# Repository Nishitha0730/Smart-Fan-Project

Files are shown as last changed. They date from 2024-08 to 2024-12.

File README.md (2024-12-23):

# About my first project on Semester 2 

# Smart Fan Project

Our Smart Fan is a temperature and occupancy-based automation system designed to optimize energy efficiency in public spaces. The project addresses the common issue of fans being left on unnecessarily, either due to forgetfulness or lack of automation.

Motivation
This project was inspired by the need to reduce energy wastage in public places where fans often operate even without human presence. By automating fan operation based on temperature and occupancy, the Smart Fan provides a more sustainable and user-friendly solution.

My Contribution
1. Enclosure Design
Designed a durable and stable enclosure using SolidWorks to support the weight of the fan motor and the rotational forces of the fan.
Due to 3D printer size constraints (24 cm height limit), the enclosure was split into two parts for manufacturing.
Utilized epoxy plastic glue and screws to securely join the two printed parts.
2. Circuit Diagram Development
Contributed to designing the circuit diagram, ensuring smooth integration with sensors and the fan's control system.

Through this project, I developed skills in enclosure design, 3D printing, and basic circuit design. These experiences have strengthened my foundation in hardware development and collaboration in team projects.

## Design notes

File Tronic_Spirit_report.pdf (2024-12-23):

## University of Moratuwa

## Faculty of Engineering

## Department of Electronic and Telecommunication Engineering


## EN 1190:Engineering Design Project

## Tronic Spirit

## Automatic Fan Controlling System along with Typical Fan Controller

Group Members

Index No | Name
220379N | Malshan K.K.R
220380J | Manawadu.D.N
220498D | Rajakaruna.R.W.M.D.S
220481U | Pitigala P.K.N.W.

## ABSTRACT

Our automatic fan controller is designed to minimize electricity wastage by regulating fan usage, particularly in public settings. The fan is designed to power down automatically in the absence of human presence, effectively reducing energy wastage. Additionally, it has the capability to adapt its speed based on external temperatures automatically, thus providing added convenience to users, especially during busy moments. This product is suitable for countries like Sri Lanka, where energy conservation is crucial. Moreover, its automatic speed adjustment feature further enhances user convenience. We plan to collaborate with major fan manufacturers to integrate our product into their fan systems. In our upcoming projects, we aim to enhance the standard fan controller and extend our project concept to include ceiling fans and wall-hanging fans.

## Table of Contents

### 1 Problem Description

### 1.1 Arriving at a Problem

We often see electronic equipment such as fans working in public places even when people aren’t around, resulting in energy wastage. Additionally, adjusting the fan’s speed during busy moments can be quite bothersome. Our product addresses these issues and provides an innovative solution.

### 1.2 Arriving at a Solution

Our automatic fan is designed to detect the presence of humans in a certain area and automatically power down when no one is detected in the vicinity. This helps reduce energy wastage by automatically turning off the fan when unnecessary. Our system also adjusts the fan speed according to the external temperature, eliminating the need for manual intervention.

### 1.3 Motivation

Seeing how fans and other electronic equipment were vainly switched on in public places such as lecture halls motivated us to create this product. The product aims to improve energy efficiency, reduce costs, and enhance user convenience.

### 1.4 Justification for Selection

We conducted a survey aimed at potential users, and the results validated our product. The survey revealed that the majority of respondents have noticed fans working unnecessarily in public places, admitted to forgetting to switch fans off when leaving, and found manually adjusting fan speed troublesome. Therefore, the survey justifies the importance of our product.

### 2 Feasibility

### 2.1 Technical Feasibility

### 2.1.1 Hardware Feasibility

Our product utilizes sensors to monitor temperature and human presence. We used two PIR sensors (Passive Infrared sensors) to detect human presence and selected the DHT11 temperature sensor to accurately track room temperature. The ATMEGA 328 microcontroller processes sensor data and controls the fan. Other hardware components include relays and push-button switches. The PCB interconnects all modules, and all hardware components are easily accessible and cost-effective, making our product feasible.

### 2.1.2 Software Feasibility

Our product was designed using Altium Designer and we used LTSPICE for simulations. We used Arduino IDE to program the microcontroller and SolidWorks for enclosure design. The software used is easy to use, making the product highly feasible in terms of software.

### 2.2 Economic Feasibility

Our product offers long-term benefits, such as lower electricity bills due to reduced energy consumption and a positive environmental impact with a lower carbon footprint, resulting in environmental sustainability. Although the initial cost might be higher than traditional fans, the long-term energy savings and environmental benefits make it economically feasible. The growing demand for smart home and office solutions further enhances its economic viability.

### 3 Architecture

The arrangement of the relays, configuration of the power supply unit, and microcontroller chip are as follows:

### 3.1 Subsystems Included in the Design

- Power Supply Module: Powers all components.
- Sensing Module: Includes sensors like the DHT11 temperature sensor and the PIR sensor used to monitor environmental parameters and detect human presence, respectively.
- Actuation Module: Connected to the microcontroller’s output pins and power supply, includes relays that regulate the fan’s speed and power based on sensor signals.
- User Interface Module: Includes the control panel with buttons for manual control, connected to the microcontroller to receive user inputs.
- Main PCB: Connects all components and subsystems with the microcontroller.

### 3.2 Wiring Diagram

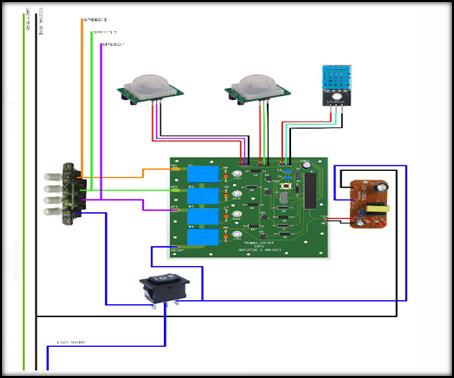
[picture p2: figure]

Figure 1: Overall Wiring Diagram

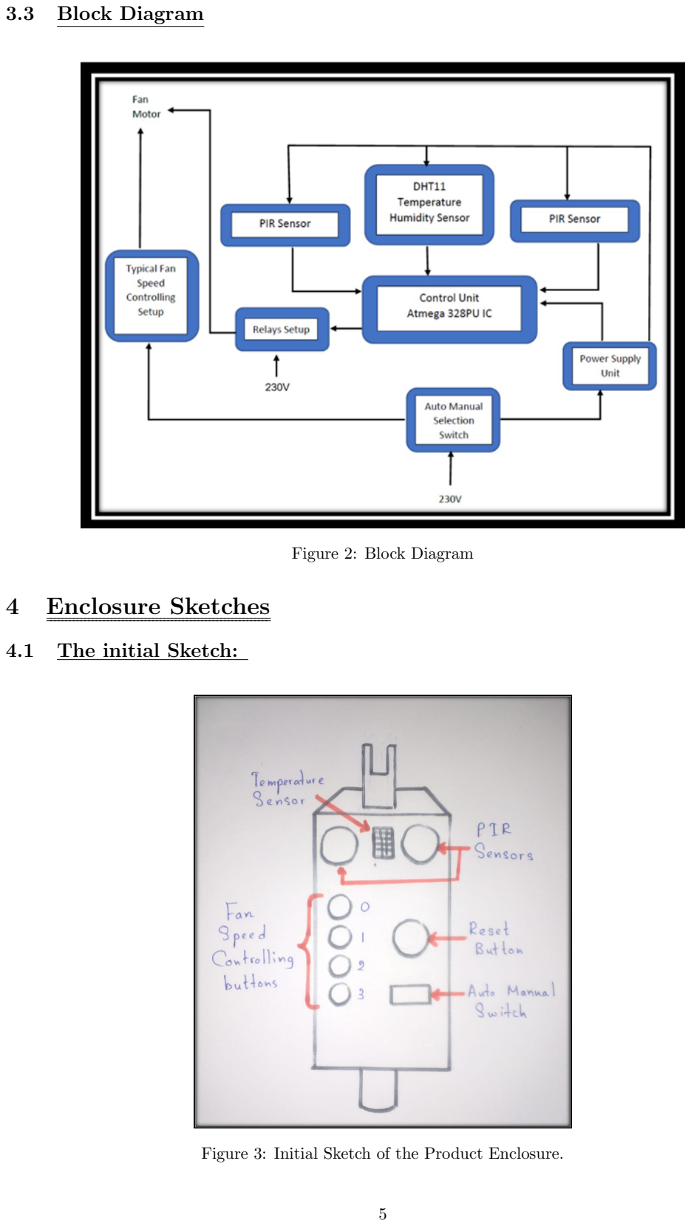
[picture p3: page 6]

### 3.3 Block Diagram

Figure 2: Block Diagram

### 4 Enclosure Sketches

### 4.1 The initial Sketch:

Figure 3: Initial Sketch of the Product Enclosure.

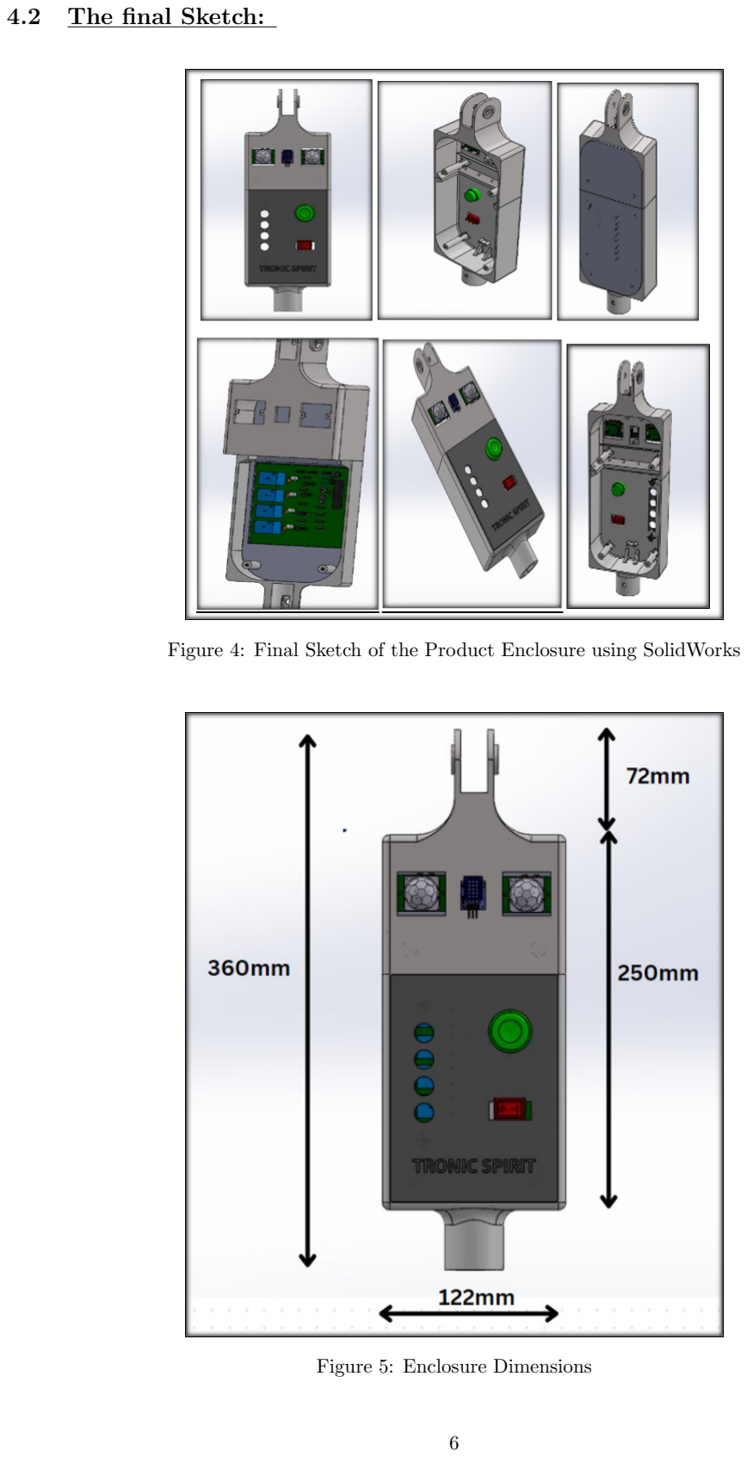
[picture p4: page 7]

### 4.2 The final Sketch:

Figure 4: Final Sketch of the Product Enclosure using SolidWorks

Figure 5: Enclosure Dimensions

### 5 PCB Design

### 5.1 PCB layout

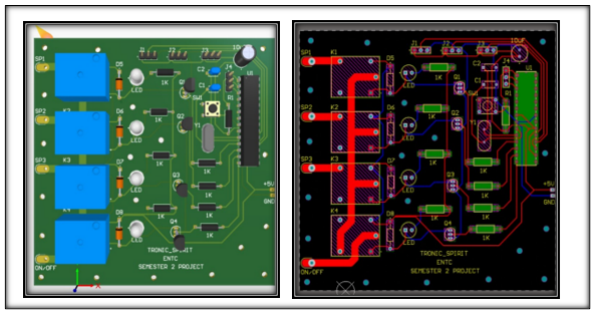
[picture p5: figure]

Figure 6: PCB Layout

### 5.2 PCB Schematic

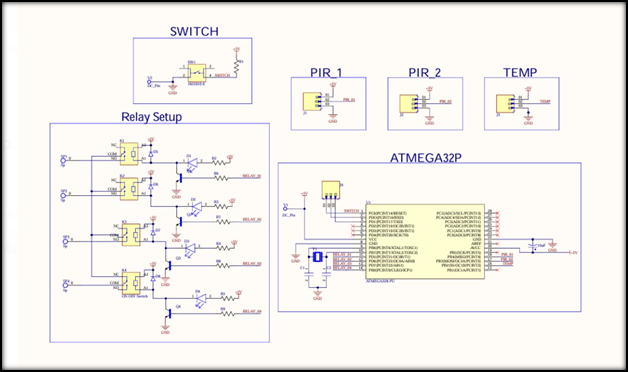
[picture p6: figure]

Figure 7: PCB Schematic

### 6 Final Product

The final product has a simple interface that makes it easy for customers to use. It includes an auto-manual switch that allows the user to select their preferred mode. In manual mode, the user can operate the fan using the panel of buttons, while auto mode allows for automatic operation.

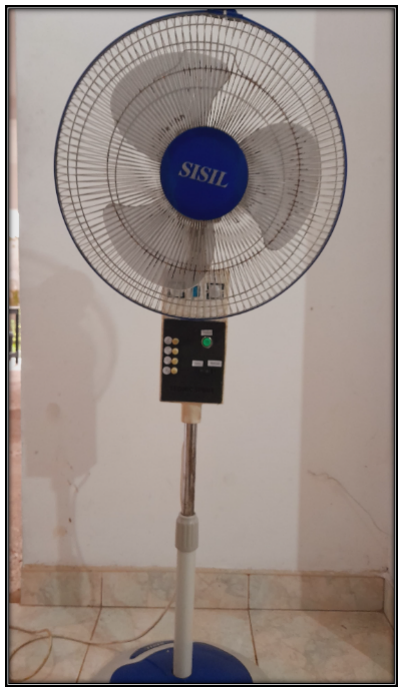
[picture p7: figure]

Figure 8: Final Product

### 7 Marketing, Sales, and After-Sales Considerations

### 7.1 Marketing

The marketing strategy for the automatic fan control system targets residential consumers, commercial spaces, and smart home enthusiasts. It emphasizes the fan’s energy efficiency and convenience. We plan to advertise our product through online advertising, content marketing and collaborating with industry-leading fan suppliers. The aim is to educate consumers, highlight the fan’s ability to optimize comfort while reducing energy costs and position the product as a practical and sustainable solution for modern homes and businesses.

### 7.2 Sales

The sales strategy uses both online and offline channels to reach a wide audience. This includes e-commerce platforms, electronics retailers, direct sales through the company’s website, social media promotional offers, and targeted sales campaigns.

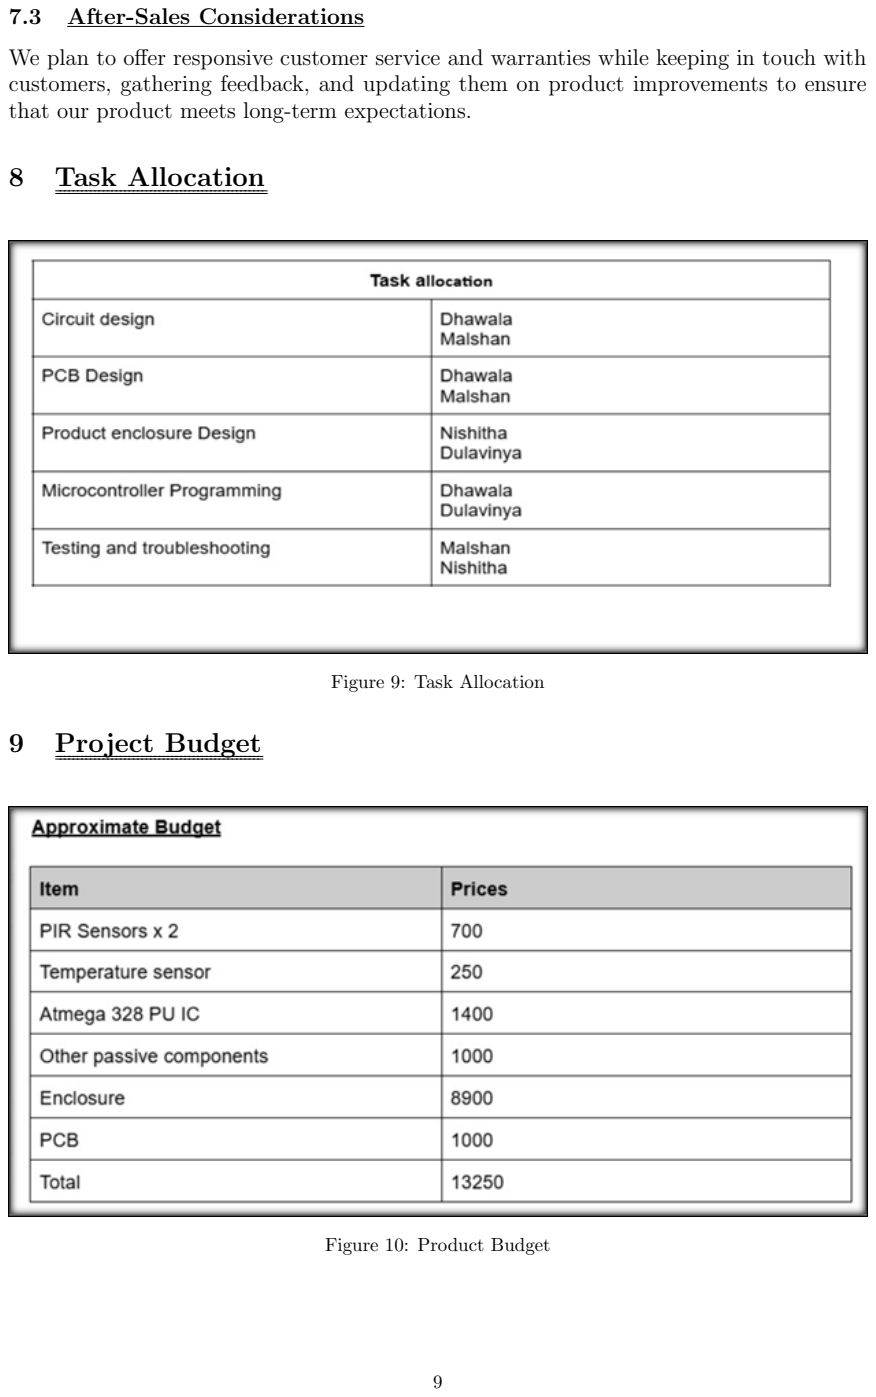
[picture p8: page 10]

### 7.3 After-Sales Considerations

We plan to offer responsive customer service and warranties while keeping in touch with customers, gathering feedback, and updating them on product improvements to ensure that our product meets long-term expectations.

### 8 Task Allocation

Figure 9: Task Allocation

### 9 Project Budget

Figure 10: Product Budget

### 10 Power consumption

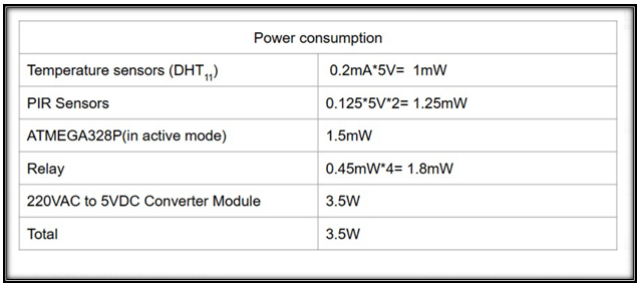
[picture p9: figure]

Figure 11: Power consumption

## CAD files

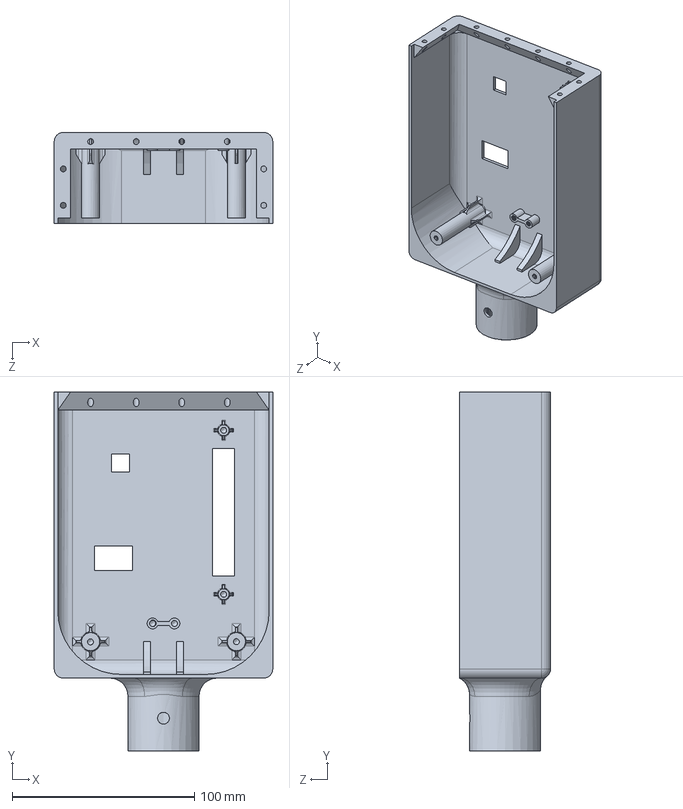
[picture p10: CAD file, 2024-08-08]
final_Part_02_june_10.SLDPRT
120.0 x 197.0 x 50.0 mm

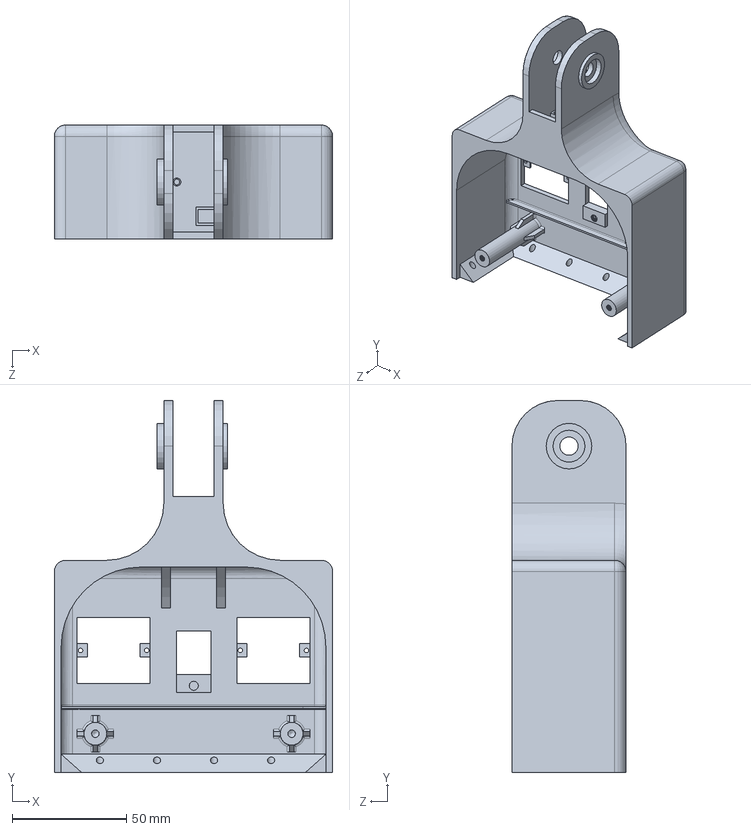
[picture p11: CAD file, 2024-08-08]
final_Part_01.SLDPRT
122.0 x 163.0 x 50.0 mm

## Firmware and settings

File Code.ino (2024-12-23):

#include <DHT.h>

#define DHTPIN 10    
#define DHTTYPE DHT11 

const int Speed1 = 7;
const int Speed2 = 6;
const int Speed3 = 5;

const int pirPin1 = 12; 
const int pirPin2 = 11; 

const int FANONOFF = 8; 

const unsigned long PIRDuration = 300000; // 5 minutes in milliseconds
const unsigned long TEMPDuration = 60000; // 1 minutes in milliseconds

unsigned long previousReadPIR = 0; 
unsigned long previousReadTEMP = 0;

DHT dht(DHTPIN, DHTTYPE);

float temperatureSum = 0.0;
int temperatureCount = 0;
float previousAverageTemp = 0.0;

void setup() {
  Serial.begin(9600);
  dht.begin();
  
  pinMode(pirPin1, INPUT);
  pinMode(pirPin2, INPUT);
  
  pinMode(FANONOFF, OUTPUT);
  pinMode(Speed1, OUTPUT);
  pinMode(Speed2, OUTPUT);
  pinMode(Speed3, OUTPUT);

  digitalWrite(FANONOFF, LOW);
  setFanSpeed(1);
}

void loop() {
  int pirState1 = digitalRead(pirPin1); 

  int pirState2 = digitalRead(pirPin2);

  unsigned long currentMillis = millis();
  
  // Read temperature and accumulate for averaging
  float temperature = dht.readTemperature();
  if (!isnan(temperature)) {
    temperatureSum += temperature;
    temperatureCount++;
  }

  // PIR sensor logic
  if (pirState1 == HIGH || pirState2 == HIGH) { 
    
    Serial.println("Motion detected!");
    if(pirState1==HIGH){
    Serial.println("PIR right detected!");
    }
    if(pirState2==HIGH){
    Serial.println("PIR left  detected!");
    }
    previousReadPIR = currentMillis;
    delay(1000);
  } else {
    if (currentMillis - previousReadPIR < PIRDuration) {
      digitalWrite(FANONOFF, LOW);
      Serial.println("KEEP ON!");
    } else {
      digitalWrite(FANONOFF, HIGH);
      Serial.println("FAN OFF!");
      setFanSpeed(0);
      // Avoid infinite loop, instead reset the previous read time
      while(true){}
      previousReadPIR = currentMillis - PIRDuration;
    }
  }

  // Temperature adjustment logic
  if (currentMillis - previousReadTEMP >= TEMPDuration) {
    previousReadTEMP = currentMillis;
    if (temperatureCount > 0) {
      float averageTemperature = temperatureSum / temperatureCount;
      Serial.print("Average Temperature: ");
      Serial.print(averageTemperature);
      Serial.println(" °C");
      previousAverageTemp = averageTemperature;
      adjustFanSpeed(previousAverageTemp);
      // Reset temperature accumulation
      temperatureSum = 0.0;
      temperatureCount = 0;
    }
  }
}

void setFanSpeed(int speed) {
  digitalWrite(Speed1, speed == 1 ? HIGH : LOW);
  digitalWrite(Speed2, speed == 2 ? HIGH : LOW);
  digitalWrite(Speed3, speed == 3 ? HIGH : LOW);
}

void adjustFanSpeed(float temperature) {
  if (temperature < 25.0) {
    setFanSpeed(1);
  } else if (temperature < 30.0) {
    setFanSpeed(2);
  } else {
    setFanSpeed(3);
  }
}
